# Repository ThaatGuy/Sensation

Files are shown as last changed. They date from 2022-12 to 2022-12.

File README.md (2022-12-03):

# Sensation
In this project we aim to develop a wearable system to guide the blind around streets, helping them avoid obstacles and get from one place to another. This report outlines a system developed that is strapped onto the users chest. Containing a Jetson Nano that processes the information coming from a camera and a GNSS module. It also provides haptic and audio feedback to guide the user through another extension board that has been developed.

To keep all the components together, a main frame made of acrylic is laser such that the cases and adaptors that are 3D printed can hold the Jetson Nano, battery pack, GNSS module and the camera. Spaces have also been cut such that straps can be attached to go around the chest and neck of the user.

The Jetson Nano uses a camera to capture the the scene and make sense of it to guide the user. To do this, each frame captured by the camera is segmented using cityscapes primarily segmenting out the road and footpaths. Mobilnet-ssd is also used to detect objects such that the user can avoid them. After the implementation the system is able to detect objects well, however is not able to segment the road and the footpath very well as cityscapes was mainly designed to detect the road. A secondary PCB board has also been developed to control 8 vibration motors that attaches to the Jetson Nano, however with the current demo only 3 of them are used and are able to guide the user to move straight, right and left.

To navigate from one location to another the system uses a GNSS module to obtain the users location and the Open-Route-Services API to determine the best route and provide some prior information about the route to optimize the system performance.

For a more detailed description on this project and how to set the system up please refer to the report on this repository.

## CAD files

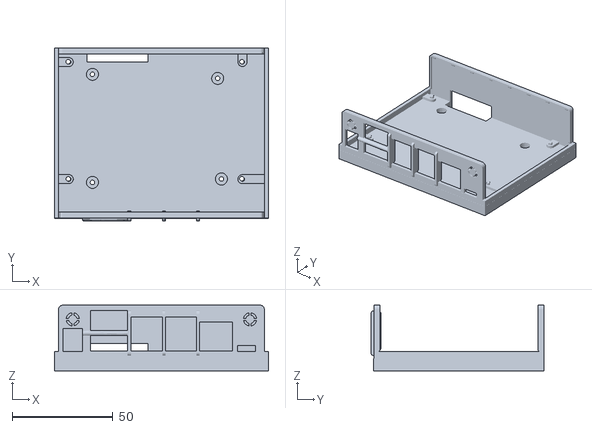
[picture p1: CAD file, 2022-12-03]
CAD/NanoBase.stl
106.0 x 85.8 x 32.5

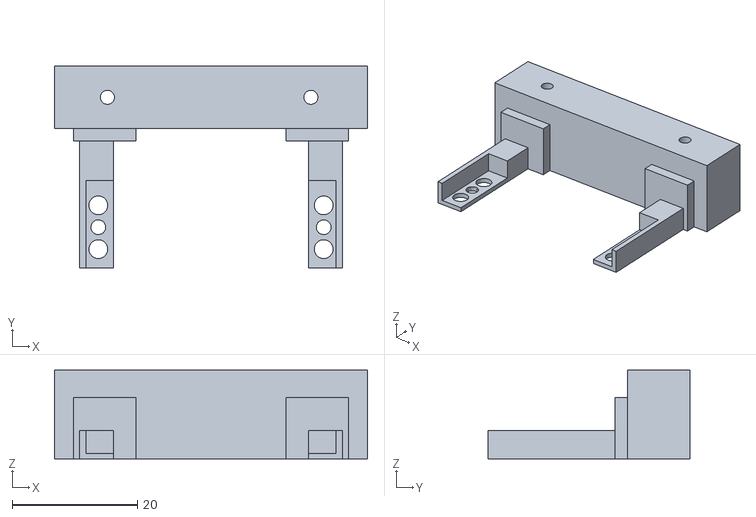
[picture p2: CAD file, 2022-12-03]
CAD/camMount.stl
50.0 x 32.2 x 14.2

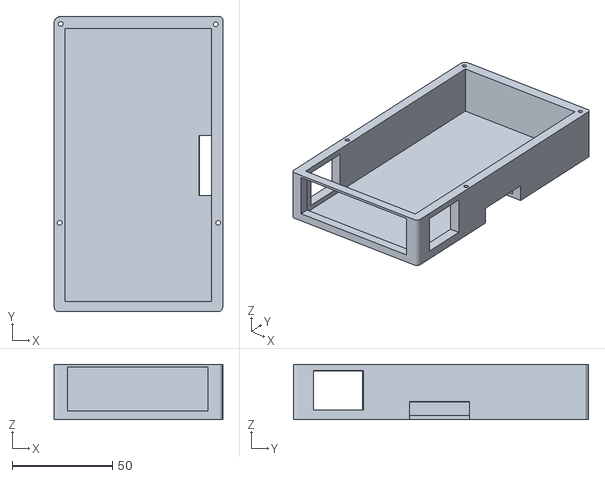
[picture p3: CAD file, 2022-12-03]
CAD/batteryCaseBase.stl
84.0 x 147.0 x 27.5

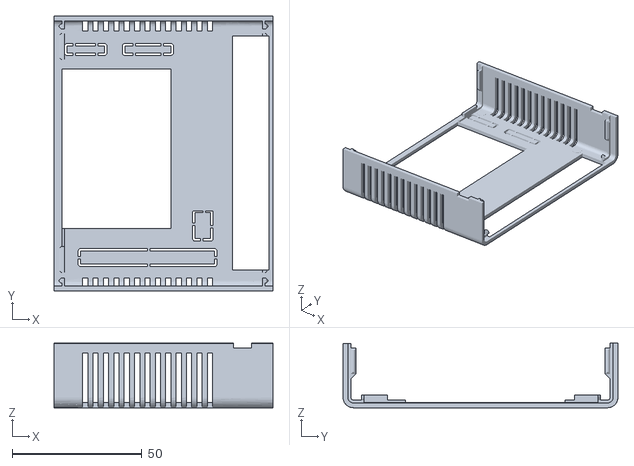
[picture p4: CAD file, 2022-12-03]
CAD/NanoCover.stl
84.3 x 105.9 x 24.8

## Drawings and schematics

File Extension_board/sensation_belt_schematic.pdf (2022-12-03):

# PWM Generation for Motors (I2C Adr. 1[A5-A0][R/W]) Jetson Nano Interface

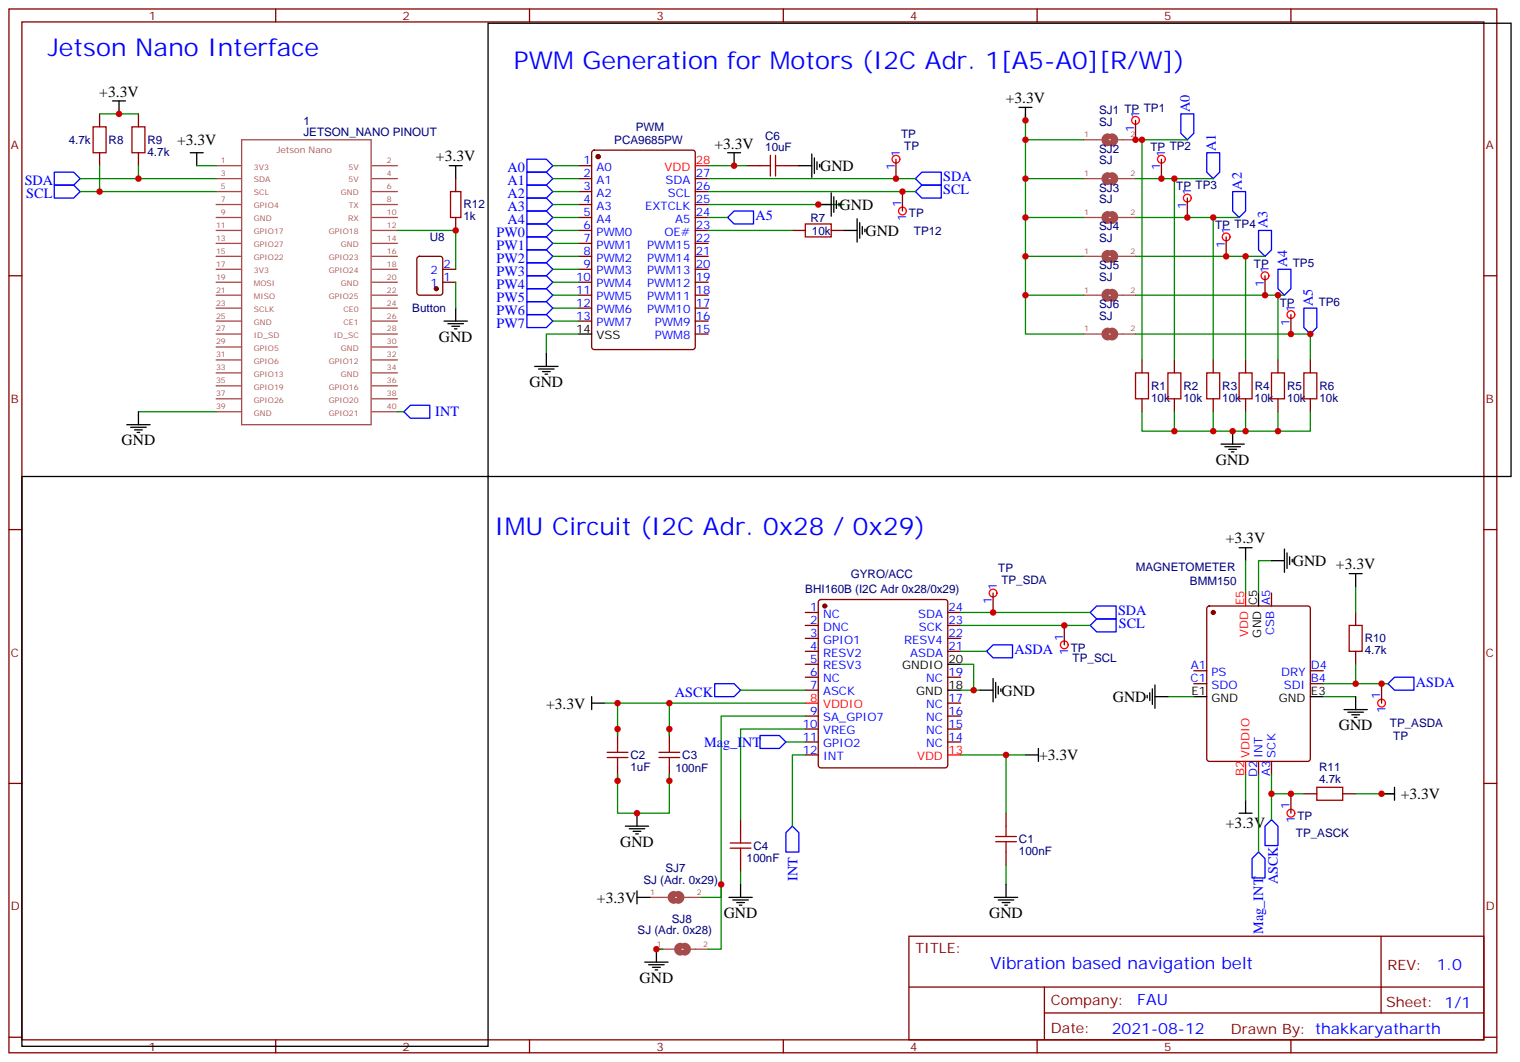
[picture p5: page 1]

# Motor Driver Circuits

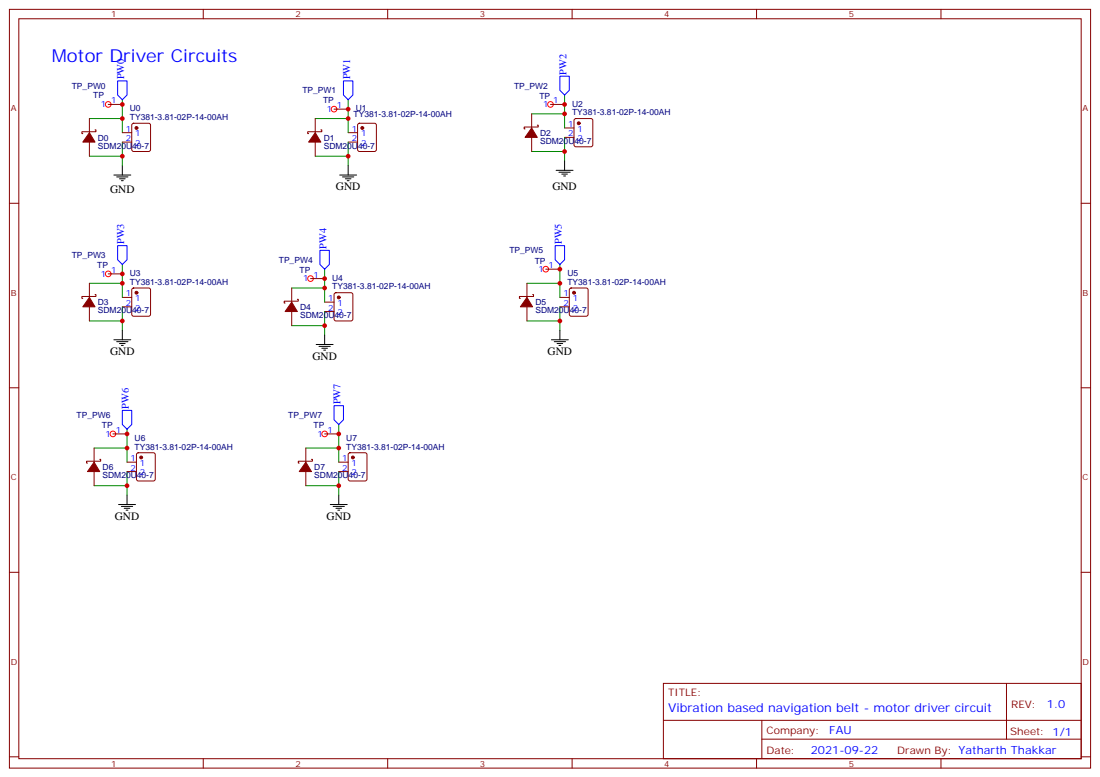
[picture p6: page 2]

Drawn By: Yatharth Thakkar

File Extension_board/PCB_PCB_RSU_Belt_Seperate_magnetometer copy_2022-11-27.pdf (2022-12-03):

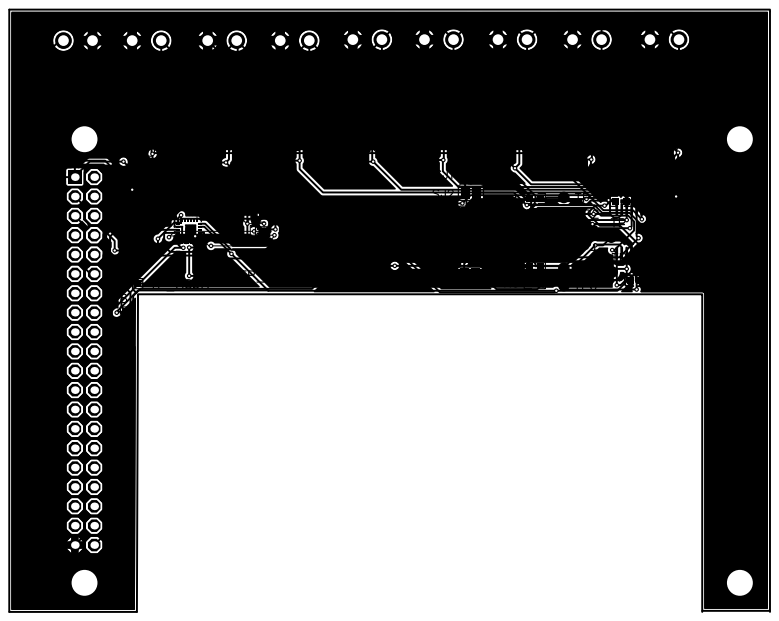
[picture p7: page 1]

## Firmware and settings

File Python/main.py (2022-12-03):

#!/usr/bin/python3

import jetson.inference
import jetson.utils

import cv2 #image processing
import argparse
import sys
import Motor #control motors
import time
import GPS
import openrouteservice as ors #navigation
import pyttsx3 # text to speech output
import geopy.distance
import csv #logging

import Jetson.GPIO as gpio # interface jetson nanos gpio
import subprocess, os
import signal

from segnet_utils import * #utilities for segmentation


# dictionary of instructions provided by ORS
instrDict = {
    0 : 'left',
    1 : 'right',
    2 : 'sharp left',
    3 : 'sharp right',
    4 : 'straight left',
    5 : 'straight right',
    6 : 'straight',
    7 : 'enter roundabout',
    8 : 'exit roundabout',
    9 : 'u-turn',
    10 : 'goal',
    11 : 'depart',
    12 : 'KL',
    13 : 'KR'
}

# dictionary for different way types provided by ORS
wayTypeDict = {
    0 : 'unknown',
    1 : 'state road',
    2 : 'road',
    3 : 'street',
    4 : 'path',
    5 : 'track',
    6 : 'cycleway',
    7 : 'footway', 
    8 : 'steps',
    9 : 'ferry',
    10 : 'construction'
}

# set up the vibration motors
motor = Motor.Motor()

# turn all motors off
motor.disengageAllMotors()

# initialize the text to speech
speech = pyttsx3.init()
# initialize the gps
gps = GPS.GPS()

# assign inpit pin for startup button
pinIn = 'DAP4_SCLK'

# indicate if detection/navigation system is running
start = 0

# parse the command line
parser = argparse.ArgumentParser(description="Segment a live camera stream using an semantic segmentation DNN.", 
                                 formatter_class=argparse.RawTextHelpFormatter, epilog=jetson.inference.segNet.Usage() +
                                 jetson.utils.videoSource.Usage() + jetson.utils.videoOutput.Usage() + jetson.utils.logUsage())

parser.add_argument("input_URI", type=str, default="/dev/video0 ", nargs='?', help="URI of the input stream")
parser.add_argument("output_URI", type=str, default="savedVideo.mp4", nargs='?', help="URI of the output stream")
parser.add_argument("--network", type=str, default="fcn-resnet18-cityscapes", help="pre-trained model to load, see below for options")
parser.add_argument("--filter-mode", type=str, default="linear", choices=["point", "linear"], help="filtering mode used during visualization, options are:\n  'point' or 'linear' (default: 'linear')")
parser.add_argument("--visualize", type=str, default="overlay,mask", help="Visualization options (can be 'overlay' 'mask' 'overlay,mask'")
parser.add_argument("--ignore-class", type=str, default="void", help="optional name of class to ignore in the visualization results (default: 'void')")
parser.add_argument("--alpha", type=float, default=150.0, help="alpha blending value to use during overlay, between 0.0 and 255.0 (default: 150.0)")
parser.add_argument("--stats", action="store_true", help="compute statistics about segmentation mask class output")

is_headless = ["--headless"] if sys.argv[0].find('console.py') != -1 else [""]

try:
	opt = parser.parse_known_args()[0]
except:
	print("")
	parser.print_help()
	sys.exit(0)

# define target longitude and latitude info
targetLongi = 11.0086529
targetLati = 49.596501

# load the segmentation network
net = jetson.inference.segNet(opt.network, sys.argv)
net1 = jetson.inference.detectNet("ssd-mobilenet-v2", threshold=0.5)

# set the alpha blending value
net.SetOverlayAlpha(opt.alpha)

# create video output
output = jetson.utils.videoOutput(opt.output_URI, argv=sys.argv+is_headless)

# create buffer manager
buffers = segmentationBuffers(net, opt)

# create video source
input = jetson.utils.videoSource(opt.input_URI, argv=sys.argv)

# work with the raw classification grid dimensions
grid_width, grid_height = net.GetGridSize()	
num_classes = net.GetNumClasses()

# allocate a single-channel uint8 image for the class mask
class_mask = jetson.utils.cudaAllocMapped(width=grid_width, height=grid_height, format="gray8")

# setup gpio
try:
	# Set pin as input pin
	gpio.setup(pinIn, gpio.IN)

	# wait for button press event
	while True:
		if not 'event' in locals():
			event = gpio.add_event_detect(pinIn, gpio.RISING, bouncetime=1000)
			print(start)

		# if button press has been detected...
		else:
			# if butten has been pressed and programme is not running start program
			if gpio.event_detected(pinIn) and start == 0:
				start = 1
				# initialize
				prevTime = time.monotonic()
				prevInstruction = ''
				# indicate device is running at 100% duty
				motor.engageMotor('left', 100)
				time.sleep(2)
				motor.disengageAllMotors()
				motor.engageMotor('straight', 100)
				time.sleep(2)
				motor.disengageAllMotors()
				motor.engageMotor('right', 100)
				time.sleep(2)
				motor.disengageAllMotors()

				# initialize
				prevTime = time.monotonic()
				prevInstruction = ''
				motor.disengageAllMotors()

				longi, lati = 0.0, 0.0
				# open file for location logging
				with open("data.csv","w") as f:
					gpsLogger = csv.writer(f,delimiter=",")
					# determing full route info
					longi, lati = gps.getLocation(speech)
					print(longi)
					if longi != 0:
						coordinates = [[longi, lati], [targetLongi, targetLati]]
						gpsLogger.writerow([lati,longi])

						try:
					        # get directions
							client = ors.Client(key='5b3ce3597851110001cf6248c2ecac6a05ad444bb520fd5f33245545') # Specify your personal API key
							route = client.directions(coordinates=coordinates,
							                          profile='foot-walking',
							                          extra_info = ['steepness', 'waytype'],
							                          format='geojson')
							completeWaytype= list(route['features'][0]['properties']['extras']['waytypes']['values'])
							completeRoute = list(route['features'][0]['properties']['segments'][0]['steps'])
							completeGeometry = enumerate(route['features'][0]['geometry']['coordinates'])

							print(len(completeRoute))
							print(completeRoute)

							for instruction in completeRoute:
								print(instruction)
								print(instruction['instruction'],instruction['distance'], instruction['type'])
								speech.say(instruction['instruction']) 
								speech.runAndWait()
								speech.say(' walk ')
								speech.runAndWait()
								speech.say(instruction['distance'])
								speech.runAndWait()
								speech.say(' meters ')
								speech.runAndWait()

								# determine the way type
								for wayType in completeWaytype:
									if wayType[0] <= instruction['way_points'][0] and wayType[1]>= instruction['way_points'][1]:
										print(wayTypeDict[wayType[2]])
										speech.say(' on the ')
										speech.runAndWait()
										speech.say(wayTypeDict[wayType[2]])
										speech.runAndWait()

								motor.engageMotor(instrDict[instruction['type']])

								motor.engageMotor(instrDict[instruction['type']])
								time.sleep(2)
								motor.disengageMotor(instrDict[instruction['type']])

						except:
							print('can not request for directions')
							speech.say(' can not request for directions ')
							speech.runAndWait()
							motor.engageMotor('error')


						speech.say(' starting now ')
						speech.runAndWait()
						prevLongi, prevLati = longi, lati
						prevTime = time.monotonic()
						prevInstrCount  = 0

						prevReqTime = time.monotonic()
					while True:

						# direct user to avoid obsticles

						# capture the next image
						img_input = input.Capture()
						detections = net1.Detect(img_input)

						jetson.utils.cudaDeviceSynchronize ()

						# convert the frame to numpy
						frame = jetson.utils.cudaToNumpy(img_input)

						frameWidth = frame.shape[1]
						frameHeight = frame.shape[0]

						# key points for rectangle
						rectBottomHeight = frameHeight - frameHeight/9
						rectTopHeight = frameHeight- frameHeight/7
						topLeftWidth = int((frameWidth/2) - frameWidth/20 -(frameWidth/30))
						topRightWidth = int((frameWidth/2) + frameWidth/20 +(frameWidth/30))
						rectHeight = int(frameHeight - frameHeight/4)

						centerWidthRight = int(frameWidth/2 + (frameWidth/30))
						centerWidthLeft = int(frameWidth/2 - (frameWidth/30))

						# color (RGB)
						red = (255, 0, 0)
						green = (0, 255, 0)
						blue = (0, 0, 255)
						black = (0, 0, 0)

						# draw the rectangles on the frame indicating where we are sensing for obstructions
						cv2.rectangle(frame, (topLeftWidth, rectHeight), (centerWidthLeft, frameHeight), red)
						cv2.rectangle(frame, (centerWidthRight, rectHeight), (topRightWidth, frameHeight), blue)

						# if the objects detected by mobilnet overlap the rectangular region initiate the correct motor so the user can avoid the object
						motorCommandList = []
						for detection in detections:
							print(detection)
							left, top, right, bottom = detection.Left, detection.Top, detection.Right, detection.Bottom
							print(left, top, right, bottom)
							# check if the bounding box overlaps with the right rectangle
							if (left >= topRightWidth) or (right <= centerWidthRight) or (bottom <= rectHeight) or (top >= frameHeight):
								motor.disengageAllMotors()
							else:
								print('**************************************overlap*************************************************')
								motorCommandList.append('left straight')
								#Motor.Motor.engageMotor(motor, 'left straight', 100)
								#time.sleep(1)

						# check if the bounding box overlaps with the left rectangle
							if (left >= centerWidthLeft) or (right <= topLeftWidth) or (bottom <= rectHeight) or (top >= frameHeight):
								motor.disengageAllMotors()
							else:
								print('**************************************overlap*************************************************')
								#Motor.Motor.engageMotor(motor, 'right straight', 100)
								motorCommandList.append('right straight')
								#time.sleep(1)

						# engage the motors needing to be engaged
						motor.engageMotor(' '.join(motorCommandList), 100)

						# convert image back to cuda
						img_input = jetson.utils.cudaFromNumpy(frame)
						# allocate buffers for this size image
						buffers.Alloc(img_input.shape, img_input.format)

						# process the segmentation network
						net.Process(img_input, ignore_class=opt.ignore_class)

						# generate the overlay
						if buffers.overlay:
							net.Overlay(buffers.overlay, filter_mode=opt.filter_mode)

						# generate the mask
						if buffers.mask:
							net.Mask(buffers.mask, filter_mode=opt.filter_mode)

						# composite the images
						if buffers.composite:
							jetson.utils.cudaOverlay(buffers.overlay, buffers.composite, 0, 0)
							#jetson.utils.cudaOverlay(buffers.mask, buffers.composite, buffers.overlay.width, 0)

						# render the output image
						output.Render(buffers.output)

						# update the title bar
						output.SetStatus("{:s} | Network {:.0f} FPS".format(opt.network, net.GetNetworkFPS()))

						# print out performance info
						jetson.utils.cudaDeviceSynchronize()
						net.PrintProfilerTimes()

					    # compute segmentation class stats
						if opt.stats:
							buffers.ComputeStats()

						# direct the user through a route
						# get current time
						currTime = time.monotonic()

						# get current longitude and latitude info
						longi, lati = gps.getLocation(speech)

						motor.disengageAllMotors()
						if longi !=0:
							coordinates = [[longi, lati], [targetLongi, targetLati]]
							gpsLogger.writerow([lati,longi])
							# find the change in distance between 2 readings in meters
							distChange = geopy.distance.geodesic((prevLongi, prevLati),(longi, lati)).m
							print(distChange)
							# if distance change is less than 20m within 3 seconds consider it as a valid reading else take another reading
							if (6<currTime - prevTime >= 3) and (distChange < 20):
								try:
									# get directions
									route = client.directions(coordinates=coordinates,
									                          profile='foot-walking',
									                          extra_info = ['steepness', 'waytype'],
									                          format='geojson')
									newActions = list(route['features'][0]['properties']['segments'][0]['steps'])

									# get a set of key coordinates
									newGeometry = list(route['features'][0]['geometry']['coordinates'])



						            # if user is 10m away from next point of interest indicate next action
						            # distToNextAction = newActions[0]['distance']
						            # get user to perform the required action 10m beforehand
									distToNextAction = newActions[0]['distance']

									print('prev count = ' + str(prevInstrCount) + ', current action count = ' + str(len(newActions)))
									# if we have less instructions than before then consider the action complete and turn motors off
									if len(newActions) < prevInstrCount:
										motor.disengageAllMotors()
										print('disengaging motors')
										prevInstrCount = len(newActions)

									print('distToNextAction' + str(distToNextAction))
									# if the distance to the next action is less than 10 indicate to the user using motors and speech
									if distToNextAction < 10:
										nextInstruction = newActions[1]['type']
										speech.say(instrDict[nextInstruction])
										speech.runAndWait()
										motor.engageMotor(instrDict[nextInstruction])
										prevInstrCount = len(newActions)

									prevTime = currTime
									prevLongi, prevLati = longi, lati

									if (currTime - prevTime > 6) and (distChange > 20):
										motor.engageMotor('right left')
										time.sleep(1)
										motor.disengageMotor('right left')
										prevTime = currTime
										prevLongi, prevLati = longi, lati

								except:
									print('can not request for directions')
									#speech.say(' can not request for directions ')
									#speech.runAndWait()
									#Motor.Motor.engageMotor(motor, 'error')
					
						if gpio.event_detected(pinIn) and start == 1:
							start = 0
							time.sleep(1)
							motor.disengageAllMotors()
							
							break

						# exit on input/output EOS
						if not input.IsStreaming() or not output.IsStreaming():
							motor.disengageAllMotors()
							break

finally:  
	gpio.cleanup()

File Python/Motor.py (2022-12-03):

from board import SCL, SDA
import busio
import time
# Import the PCA9685 module.
from adafruit_pca9685 import PCA9685


class Motor():

	def __init__(self):
		# Create the I2C bus interface.
		self.i2c_bus = busio.I2C(SCL, SDA)

		# Create a simple PCA9685 class instance.
		self.pca = PCA9685(self.i2c_bus)

		# Set the PWM frequency to 60hz.
		self.pca.frequency = 60
		self.timer = 0

		#define which channel belongs to which motor
		self.leftMotor = self.pca.channels[7]
		self.rightMotor = self.pca.channels[5]
		self.centerMotor = self.pca.channels[6]
		print('motor')

	def engageMotor(self, command, duty=100):

		# conveet duty to be a number between 0 and 15
		dutyLevel = int(15*duty/100)

		dutyCommand = dutyLevel*4095
		print(dutyCommand)

		off = 0x0FFF
		
		if 'right' in command:
			self.rightMotor.duty_cycle = dutyCommand
			print('right')
		if 'left' in command:
			self.leftMotor.duty_cycle = dutyCommand
			print('left')
		if 'straight' in command:
			self.centerMotor.duty_cycle = dutyCommand

		if 'u-turn' in command:
			self.rightMotor.duty_cycle = dutyCommand
			print('right')
			time.sleep(0.5)
			self.rightMotor.duty_cycle = off
			self.centerMotor.duty_cycle = dutyCommand
			print('center')
			time.sleep(0.5)
			self.centerMotor.duty_cycle = off
			self.leftMotor.duty_cycle = dutyCommand
			print('left')
			time.sleep(0.5)
			self.leftMotor.duty_cycle = off

		if 'goal' in command:
			for i in range (3):
				self.rightMotor.duty_cycle = dutyCommand
				self.centerMotor.duty_cycle = dutyCommand
				self.leftMotor.duty_cycle = dutyCommand
				time.sleep(1)
				self.rightMotor.duty_cycle = off
				self.centerMotor.duty_cycle = off
				self.leftMotor.duty_cycle = off
				time.sleep(1)

		if 'error' in command:
			for i in range(5):
				self.rightMotor.duty_cycle = dutyCommand
				time.sleep(1)
				self.rightMotor.duty_cycle = off
				self.leftMotor.duty_cycle = dutyCommand
				time.sleep(1)
				self.leftMotor.duty_cycle = off

		if 'start' in command:
			for i in range(2):
				self.rightMotor.duty_cycle = dutyCommand
				time.sleep(1)
				self.rightMotor.duty_cycle = off
				self.leftMotor.duty_cycle = dutyCommand
				time.sleep(1)
				self.leftMotor.duty_cycle = off
		return


	def disengageMotor(self, command):
		off = 0x0FFF
		if 'right' in command:
			self.rightMotor.duty_cycle = off
		if 'left' in command:
			self.leftMotor.duty_cycle = off
		else:
			self.centerMotor.duty_cycle = off
		return

	def disengageAllMotors(self):
		off = 0x0FFF
		self.rightMotor.duty_cycle = off
		self.leftMotor.duty_cycle = off
		self.centerMotor.duty_cycle = off
		return
